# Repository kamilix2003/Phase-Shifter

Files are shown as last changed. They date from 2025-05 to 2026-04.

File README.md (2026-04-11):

# Interface for MAPS-010144 digital phase shifter

## Description

STM32G0B01 based board for controlling daisy-chained digital phase shifter via SPI-like serial interface. User can interface with the board either by buttons and LEDs on the board or via virtual serial port over USB, communication over serial port is realized using simple TLV protocol. The board is providing bipolar supply for the phase shifters.

<p align=center>
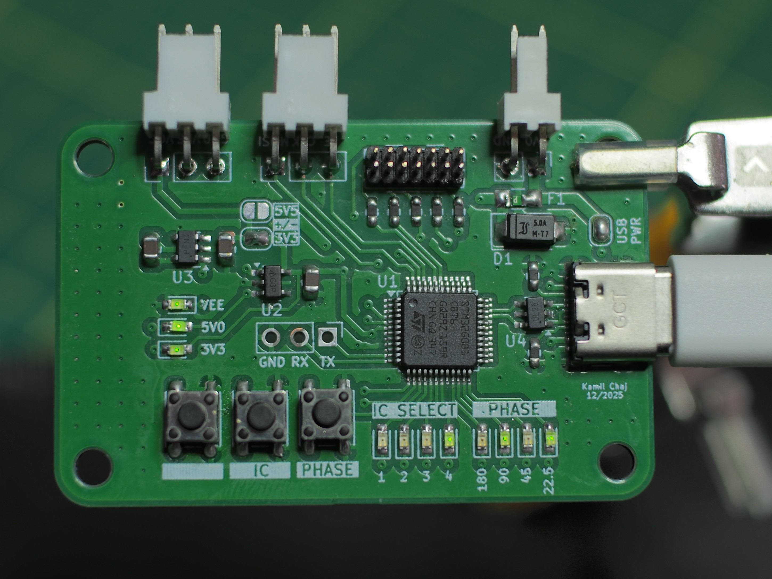
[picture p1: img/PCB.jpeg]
    
</p>

<!-- ![PCB photo](img/PCB.jpeg) -->

### Repository contents
- [KiCAD](KiCAD) - ECAD projects of all desinged PCBs for the project
- [python_api](python_api) - Simple python api for communicating with the controller via serial port
- [Src](Src) - Firmware source code separated from generated STM32 project
- [phase_shifter_measurements](phase_shifter_mesurements) - Measuremented scattering parameters of the phase shifter

## Firmware 

<p align=center>
    
</p>

<!-- ![firmware_architecture](img/firmware_architecture.drawio.svg) -->

### Serial communication

Available commands:
| **T**ype | **L**ength [bytes] | **V**alue | Description |
|---|---|---|---|
| 0x02 | 1 | command id | Ack |
| 0x10 | 4 | phase shifts (0 - 15) | Set phase |
| 0x11 | 0 | - | Transmit |
| 0x12 | 1 | latch state | Latch state |

After each message microcontroller should send ACK message with payload containing command id of original message

Example routine to set new phase delay:
1. `0x12 0x01 0x00` - make sure that latch is set low in order to accept data via serial interface
1. `0x10 0x04 0x04 0x02 0x0f 0x08` - send phase shifts to the controller
1. `0x11 0x00` - transmit phase shifts via SPI to the phase shifters
1. `0x12 0x01 0x01` - set latch to update phase shift 
1. `0x12 0x01 0x00` - reset latch

### Buttons and LEDs

The board is equiped in 3 tactile buttons and two 4-led displays where each display shows according to the silkscreen description either currently selected phase shifter or phase shift set for the selected phase shifter.
Buttons have following functions starting from the left most button:
- On short press transmits current phase shifter configuration over SPI
- On short press cycles through 4 phase shifters, on long press sets all phase shifters to 0
- On short press increments phase delay, on long press set current phase shifter to 0

<!-- # MAPS-010144 Phase Shifter Interface as Part of Phased Antenna Array

## Description

A microcontroller serves as an interface for phase control, managing multiple phase shifters connected in a daisy chain via SPI. Bidirectional communication between the PC and MCU is established via UART/USB.

## Goals

in **bold** features in scope of SKM project

- **Serial interface with IC via SPI peripheral**
- **PC-MCU communication by UART/USB (virtual COM)**
- **Controlling multiple phase shifter in daisy chain**
- Python API for controlling beam direction
- I2C bus for communication with multiple arrays where one becomes master

## Block diagram

![block diagram](img/SKM.drawio.svg)

## Docs

- [Specification](./docs/Specification.md)
- [Report](./docs/SKM_Report_Kamil_Chaj.pdf) -->

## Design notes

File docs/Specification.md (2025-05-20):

# Specification

## Communication sequence

```mermaid
sequenceDiagram
    PC->>+MCU: UART - initial frame
    MCU->>MCU: Error detection
    MCU->>PC: Report error / Response
    PC->>MCU: 
    loop from N to 1
    MCU->>+IC: SPI: phase setting
    MCU->>+IC: 
    MCU->>+IC: 
    end
    MCU->>-PC: Success / Error
```

## System diagram

```mermaid
flowchart LR

UART -- RX --> UART_b
UART_b -- End of transmission --> CRC
CRC -- Success ---> Process_frame

Process_frame -- TX --> UART
Process_frame --> SPI_b
SPI_b --> SPI
Process_frame -- Start TX --> SPI

Process_frame[Frame processing]
UART_b[UART buffer]
SPI_b[SPI buffer]

```

## SPI

Serial communication specification according to MAPS-010144 datasheet[^2]

|Pin|Description|
|---|---|
|SERIN|MOSI|
|SEROUT|MSIO - connected to the next IC|
|CLK|Clock|
|LE|Output (phase) stays constant when set LOW|
|P/S|Parallel/Serial select, HIGH for Serial|

Internal register of the IC has 6 bits, where most significant bit represent most significant phase shift

|Option|Value|
|---|---|
|Data size|6 Bits|
|Frist bit|MSB first|
|Clock period|> 100ns|
|CPOL|LOW|
|CPHA|LOW|

## UART / USB

### Frame

Full frame is built of multiple bytes where:

|Bytes |Function|
|---|---|
|Byte 1|Command ID|
|Byte 2|Payload size|
|Byte 3|Data 0|
|Byte 4|Data 1|
|Byte ...|...|
|Byte N|Data N|
|Byte N + 1|CRC|

### Commands

#### Send phase shift buffer

- Data n - phase shifter address
- Data n+1 - phase shift

#### Request phase shift buffer

- Data n - phase shifter address

#### Load phase shift buffer

- No data

#### Clear phase shift buffer

- No data

#### Error

- Data n - contains error code

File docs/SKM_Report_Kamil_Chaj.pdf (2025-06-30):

## Phase Shifter Interface

Standardy Komunikacji Międzyukładowej w modułowych systemach wbudowanych

Kamil Chaj

## 1 Introduction

This project is a part of the phased array antenna and the goal is to create a way to programmable control multiple phase shifters. Phase shifters can be controlled directly by accessing all control bits in parallel, or they can be controlled via the SPI-like protocol, which enables controlling multiple phase shifters utilizing minimal pin count. The interface with the microcontroller will be implemented using UART.

## 2 Selected MCU

The STM32 NUCLEO-G0B1RE evaluation board was chosen for this project, the main requirement was an integrated USB controller to minimize the element count on the future printed circuit board. Also, the G0 series MCU was chosen because of low price and no need for high performance of specific peripherals other than USB and SPI.

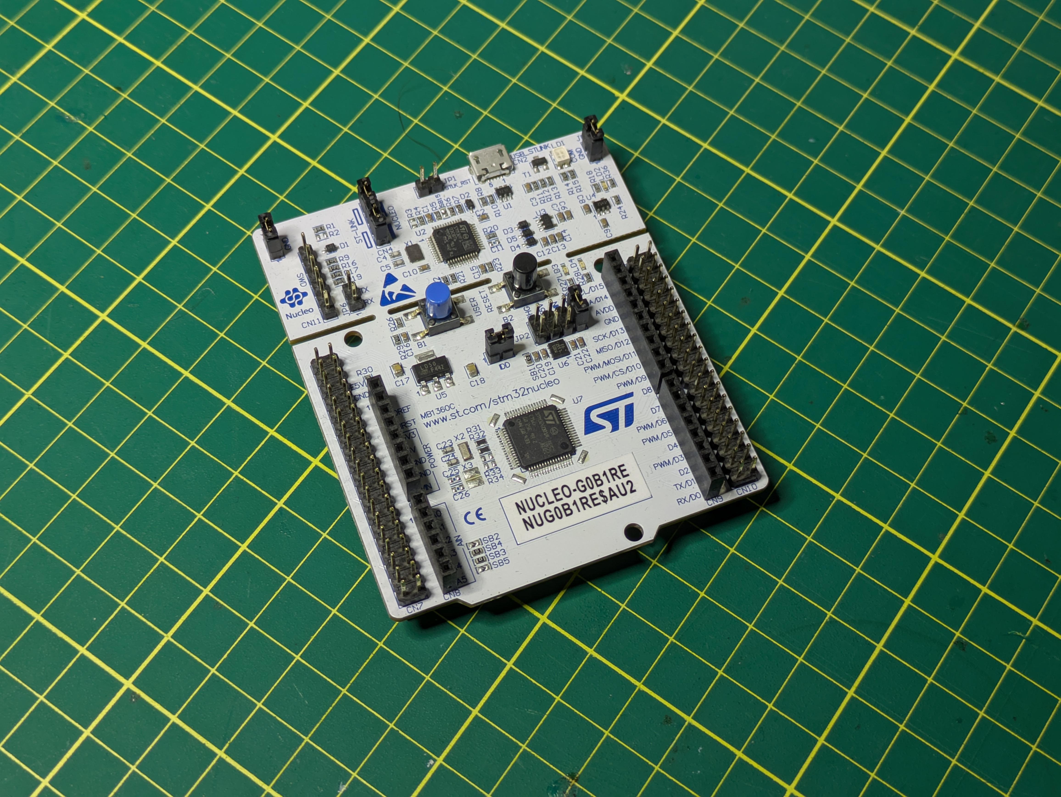
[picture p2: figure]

Figure 1: NUCLEO development board

## 3 SPI protocol

MAPS-010144 (https://cdn.macom.com/datasheets/MAPS-010144.pdf) phase shifter has a 6-bit shift register which corresponds to quantized phase shift, in the case of this particular phase shifter 2 least significant bits are not used because the maximum resolution is 4-bit. In order to update the phase shift from the register to the actual phase shift, the LE pin must be set. Phase shifters are equipped in both SERIN and SEROUT pins which allow multiple ICs to be connected in a daisy chain.
SPI peripheral was configured according to the phase shifter data sheet, data size was set at 6 bits and the transmission starts from the least significant bit; also, the baud rate was set to just 250 Kbits per second, which is much slower than what the IC can handle but what allowed easier debugging with my current measurement equipment.

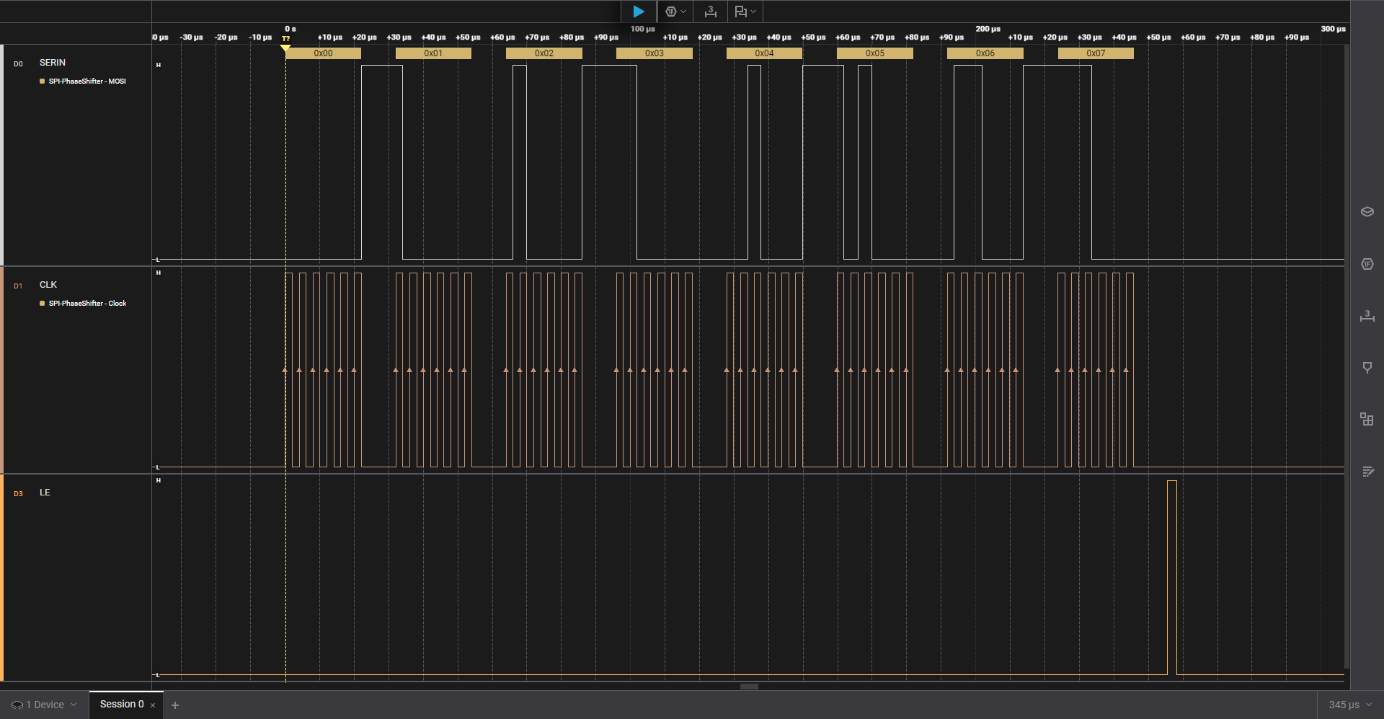
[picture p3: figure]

Figure 2: SPI communication captured with logic analyzer

## 4 USB CDC virtual COM port

Communication over virtual COM port is implemented using the USB_DEVICE middleware provided with the STM32CUBE environment, the middleware is set in the Communication Device Class (CDC) mode. Using this middleware allows for simple communication with a PC identical to UART.

### 4.1 Communication protocol

Byte 0 | Byte 1 | Byte 2 | Byte... | Byte N | Byte N+1 | Byte N+2
COMMAND ID | DATA SIZE | DATA 0 | ... | DATA N | CRC | END

Table 1: Data format

Name | Hex value | Description
OK | 0x00 | transmission successful
ECHO | 0x01 | return the same command
ERROR | 0xff | transmission failed
PHASE SHIFTER COUNT | 0x03 | set number of phase shifters
SEND BUFFER | 0x10 | begin SPI transmission
SET BUFFER | 0x11 | send new buffer
GET BUFFER | 0x12 | request current buffer
GET BUFFER RE | 0x13 | response with buffer
CLEAR BUFFER | 0x14 | set buffer to 0

Table 2: Commands

### 4.2 Cyclic redundancy check

CRC value on MCU side is calculated using integrated CRC calculation unit and the same algorithm is implement on PC side.

## 5 Implementation

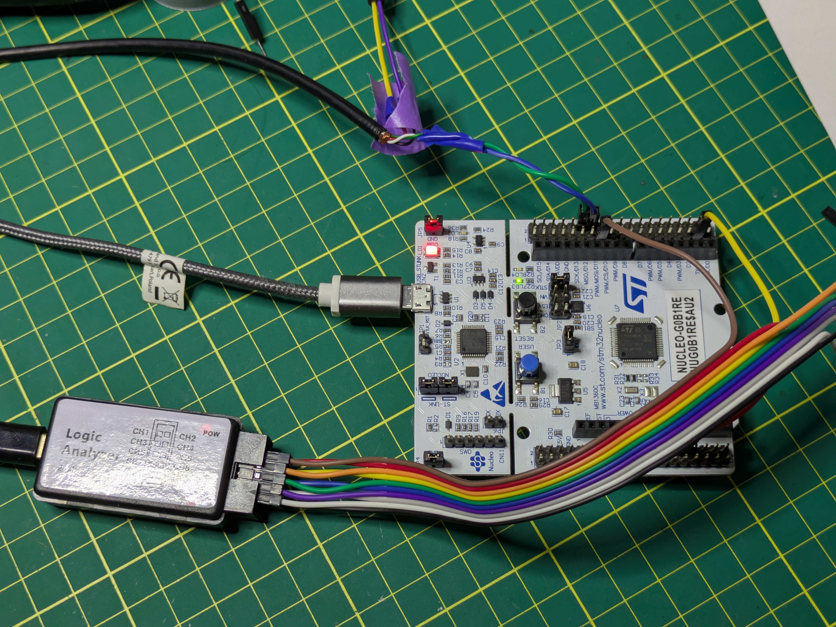
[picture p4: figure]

Figure 3: Test setup

### 5.1 Peripheral initialization

The first step of implementation was setting up the required peripherals in STM32CubeMX:

- TIM1 - timing LE pulse
- SPI1 - communication with phase shifter
- USART2 - ST-LINK virtual com port for debugging
- USB_DRD_FS - integrated USB peripheral
- CRC - CRC calculation unit
- USB_DEVICE - Middleware for USB

### 5.2 Phase shifter interface

As for typical embedded program structure, I create a typedef struct phase_shifter which holds all necessary handles and variables, and typedef enum phase_shifter_status for status type. after defining those types, I created basic functions that implement the following actions: initiation of phase_shifter, setting, getting and clearing buffer, setting the number of connected phase shifters and starting transmission.

### 5.3 PC-MCU communication

Similarly as in the previous section, I defined typedef struct command, typedef struct interface and typedef enum interface_status. The command struct is used to store and create commands in a more convenient way during processing.
Functions used for communication:
- recieve_command - dissects buffer and populates variables in command struct, verifies CRC value
- transmit_command - assembles buffer from command struct and appends CRC value
- process_command - handles received commands and sends responses to the sender

The entire communication is PC-driven, which means that MCU does something in response to the PC.

### 5.4 Python API

As mentioned in the introduction, the goal is to create a way to programmable control phase shifter therefore, I created a simple Python program that allows for sending and receiving data.

### 5.5 Block diagram

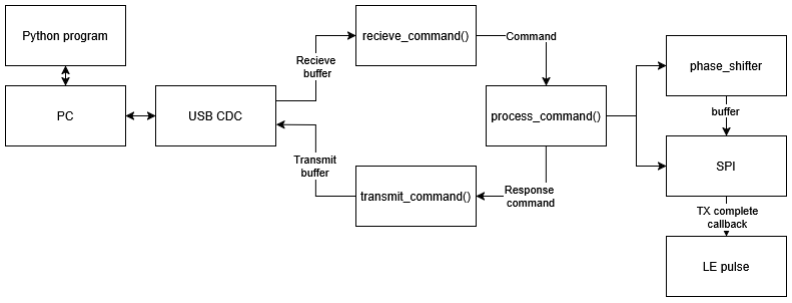
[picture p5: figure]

Figure 4: Block diagram of the program

## 6 Conclusions

This project successfully demonstrates a complete system for controlling multiple integrated circuits using embedded communication protocols. By integrating USB CDC communication, a structured command protocol, SPI data transmission, and a Python-based control API, a flexible and scalable interface was established. The modular software structure, including clear abstractions for the phase shifter interface and communication protocol, enhances maintainability and potential for future expansion.
Overall, the project fulfills its intended goals and provides a solid foundation for further development and integration into more complex RF systems.
All code available on GitHub (https://github.com/kamilix2003/phase-shifter)

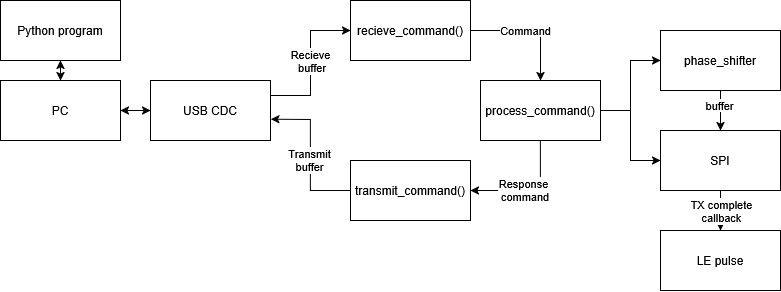
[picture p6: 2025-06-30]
img/SKM.drawio.png

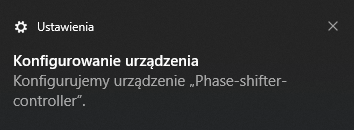
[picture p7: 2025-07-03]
img/port_name.png

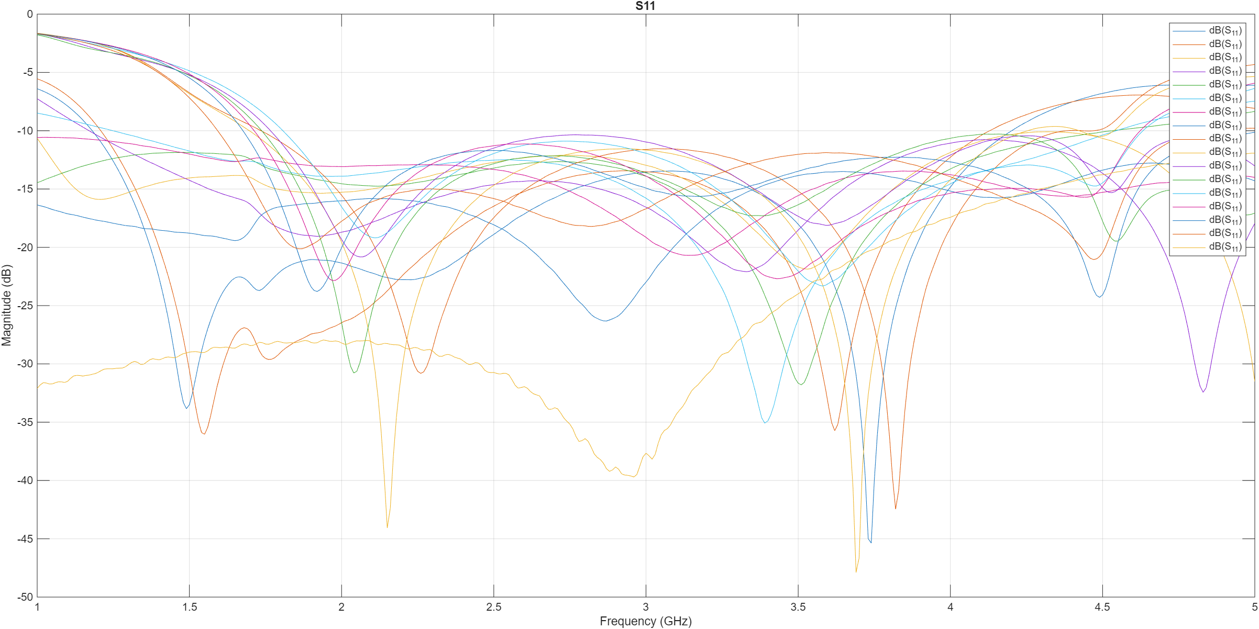
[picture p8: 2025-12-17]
phase_shifter_mesurements/s11.png

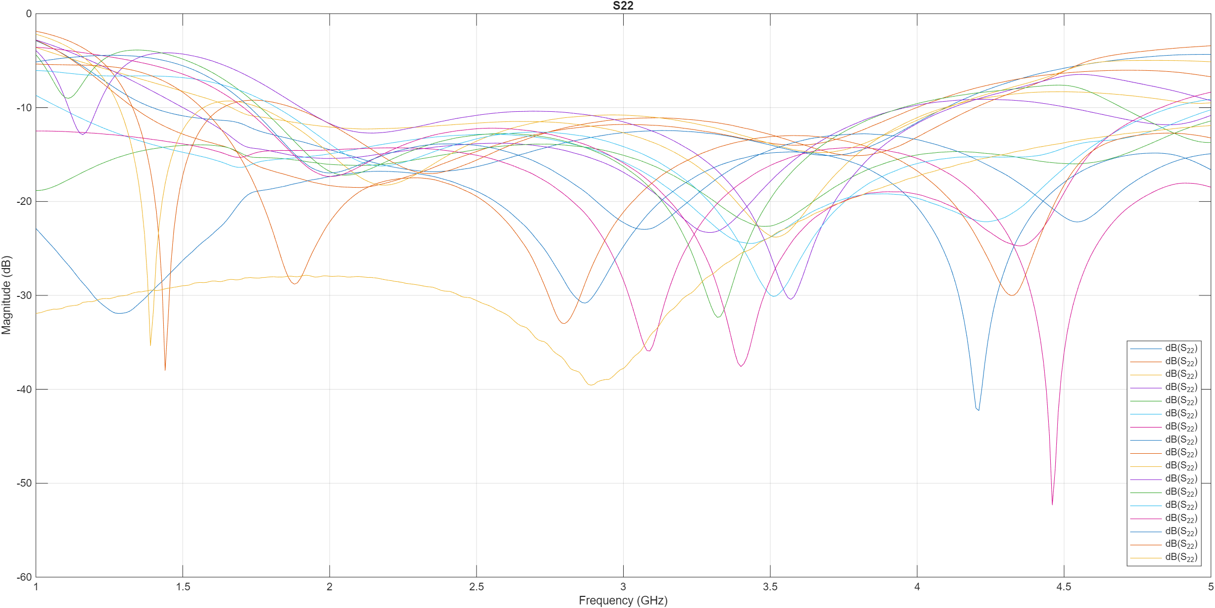
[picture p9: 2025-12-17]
phase_shifter_mesurements/s22.png

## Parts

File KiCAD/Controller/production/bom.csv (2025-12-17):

Designator | Footprint | Quantity | Value | LCSC Part #
C1, C10, C2, C3, C4, C5, C6, C7, C8, C9 | 0805 | 10 | 4.7u
C11, C12, C13, C14, C15, C16 | 0603 | 6 | 100n
D1 | D_SMA | 1 | SMAJ5.0A
D10, D11, D12, D2, D3, D4, D5, D6, D7, D8, D9 | 0603 | 11 | LED
F1 | 1206 | 1 | Polyfuse
J1 | PinHeader_2x07_P1.27mm_Vertical | 1 | Conn_ST_STDC14
J2 | USB_C_Receptacle_GCT_USB4105-xx-A_16P_TopMnt_Horizontal | 1 | USB_C_Receptacle_USB2.0_16P
J3 | PinHeader_1x02_P2.54mm_Vertical | 1 | Conn_01x02_Pin
J4, J5, J6 | PinHeader_1x03_P2.54mm_Vertical | 3 | Conn_01x03_Pin
R1, R2, R3, R4, R5 | 0603 | 5 | 100
R10, R11, R12, R13, R14, R15, R16, R17, R18, R6, R7, R8, R9 | 0603 | 13 | 5.1k
SW1, SW2, SW3 | SW_SPST_PTS647_Sx38 | 3 | SW_Push
U1 | LQFP-48_7x7mm_P0.5mm | 1 | STM32G0B1CBTx
U2 | SOT-23-5 | 1 | AP2127K-3.3
U3 | SOT-23-5 | 1 | TPS60403DBV
U4 | SOT-23-6 | 1 | USBLC6-2SC6

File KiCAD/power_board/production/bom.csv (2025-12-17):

Designator | Footprint | Quantity | Value | LCSC Part #
C1, C2, C3, C4, C5, C6, C7, C8 | 0805 | 8 | 4.7u
D1 | D_SMA | 1 | SMAJ5.0A
D2, D4 | 0603 | 2 | LED
F1 | 1206 | 1 | Polyfuse
J1 | PinHeader_1x03_P2.54mm_Vertical | 1 | Conn_01x03_Pin
J2 | PinHeader_1x02_P2.54mm_Vertical | 1 | Conn_01x02_Pin
R1, R3 | 0603 | 2 | 5.1k
U1 | SOT-23-5 | 1 | TPS60403DBV
U2 | SOT-23-5 | 1 | AP2127K-3.3

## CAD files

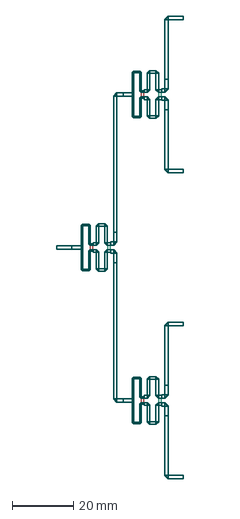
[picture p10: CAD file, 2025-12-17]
KiCAD/Feed_network/4_way_divider.dxf
41.4 x 151.1 mm

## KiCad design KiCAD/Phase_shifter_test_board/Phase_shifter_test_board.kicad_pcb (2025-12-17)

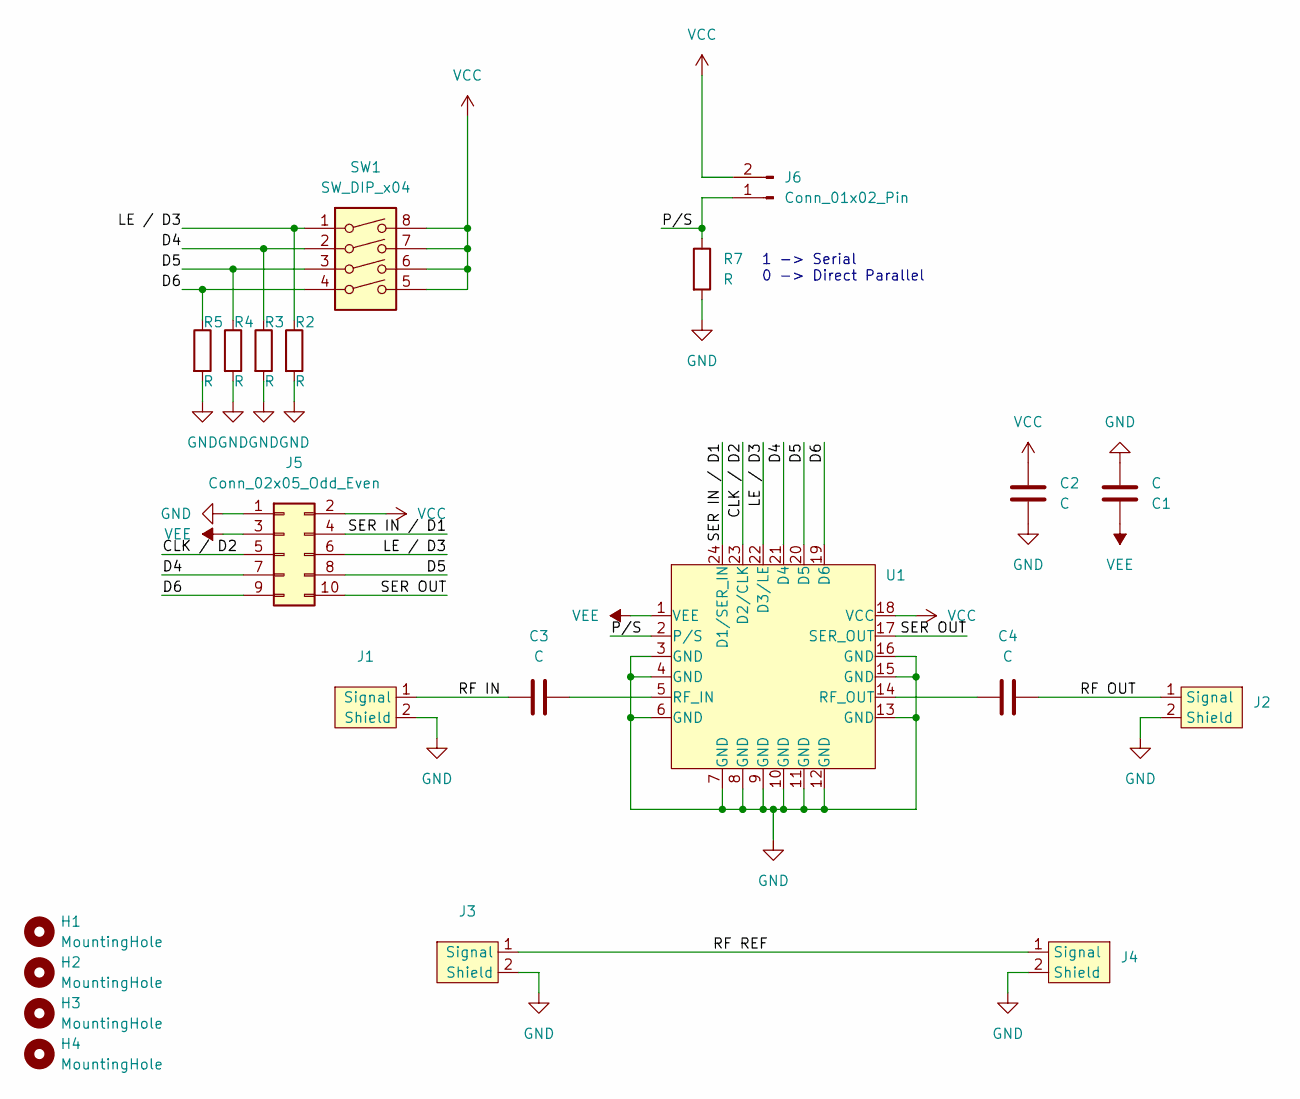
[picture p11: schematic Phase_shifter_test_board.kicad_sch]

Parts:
C1, C2, C3, C4: C; C_0603_1608Metric_Pad1.08x0.95mm_HandSolder
H1, H2, H3, H4: MountingHole; MountingHole_3.2mm_M3
J1, J2, J3, J4: Conn
J5: Conn_02x05_Odd_Even; PinHeader_2x05_P2.54mm_Vertical
J6: Conn_01x02_Pin; PinHeader_1x02_P2.54mm_Vertical
R2, R3, R4, R5, R7: R; R_0603_1608Metric_Pad0.98x0.95mm_HandSolder
SW1: SW_DIP_x04; SW_DIP_SPSTx04_Slide_9.78x12.34mm_W7.62mm_P2.54mm
U1: QFN-24_EP_4x4_Pitch0.5mm

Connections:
/CLK / D2: J5.5, U1.23 (D2/CLK)
/D4: J5.7, R3.1, SW1.2, U1.21 (D4)
/D5: J5.8, R4.1, SW1.3, U1.20 (D5)
/D6: J5.9, R5.1, SW1.4, U1.19 (D6)
/LE / D3: J5.6, R2.1, SW1.1, U1.22 (D3/LE)
/P/S: J6.1, R7.1, U1.2 (P/S)
/RF IN: C3.1, J1.1 (Signal)
/RF OUT: C4.2, J2.1 (Signal)
/RF REF: J3.1 (Signal), J4.1 (Signal)
/SER IN / D1: J5.4, U1.24 (D1/SER_IN)
/SER OUT: J5.10, U1.17 (SER_OUT)
GND: C1.2, C2.2, J1.2 (Shield), J2.2 (Shield), J3.2 (Shield), J4.2 (Shield), J5.1, R2.2, R3.2, R4.2, R5.2, R7.2, U1.3 (GND), U1.4 (GND), U1.6 (GND), U1.7 (GND), U1.8 (GND), U1.9 (GND), U1.10 (GND), U1.11 (GND), U1.12 (GND), U1.13 (GND), U1.15 (GND), U1.16 (GND)
unnamed: C3.2, U1.5 (RF_IN)
unnamed: C4.1, U1.14 (RF_OUT)
VCC: C2.1, J5.2, J6.2, SW1.5, SW1.6, SW1.7, SW1.8, U1.18 (VCC)
VEE: C1.1, J5.3, U1.1 (VEE)

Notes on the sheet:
1 -> Serial 0 -> Direct Parallel

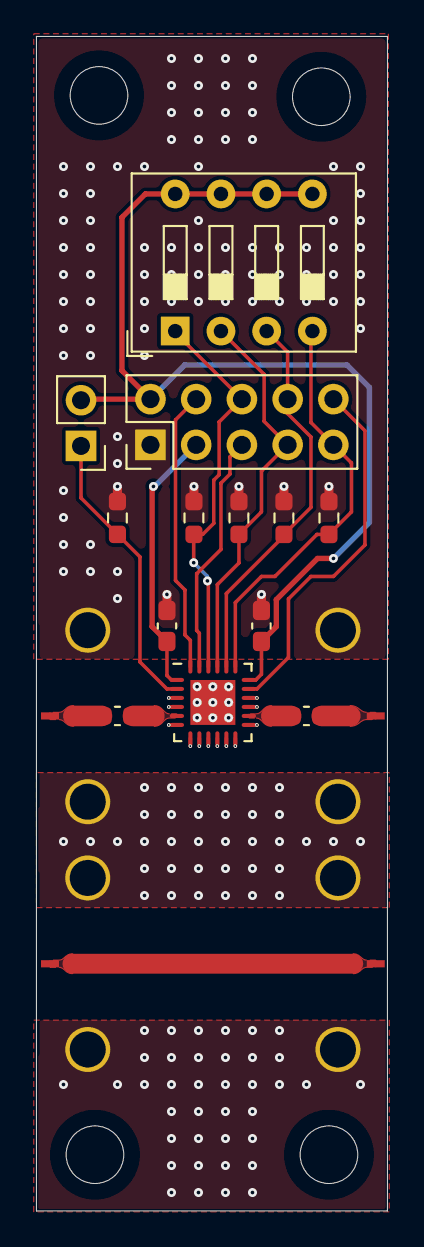
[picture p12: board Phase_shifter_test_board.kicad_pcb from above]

Board: 2 copper layers, 19.5 x 65.2 mm, 21 parts (0 on the bottom side), 16 nets.

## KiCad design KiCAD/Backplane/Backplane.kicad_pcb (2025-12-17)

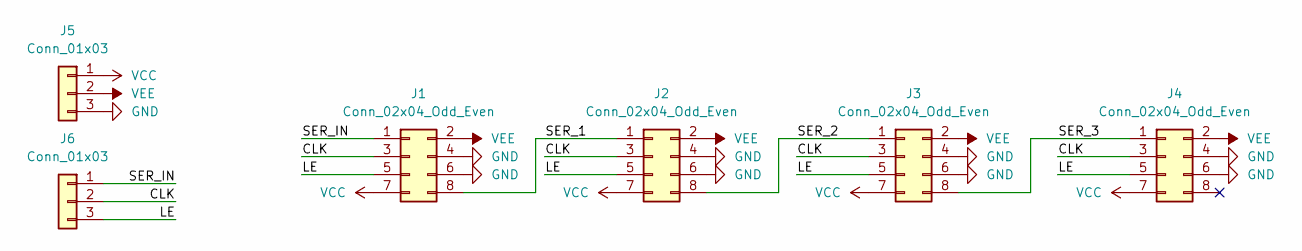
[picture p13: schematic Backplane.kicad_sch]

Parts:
J1, J2, J3, J4: Conn_02x04_Odd_Even; PinSocket_2x04_P2.54mm_Vertical
J5, J6: Conn_01x03; PinHeader_1x03_P2.54mm_Horizontal

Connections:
/CLK: J1.3, J2.3, J3.3, J4.3, J6.2
/LE: J1.5, J2.5, J3.5, J4.5, J6.3
/SER_1: J1.8, J2.1
/SER_2: J2.8, J3.1
/SER_3: J3.8, J4.1
/SER_IN: J1.1, J6.1
GND: J1.4, J1.6, J2.4, J2.6, J3.4, J3.6, J4.4, J4.6, J5.3
VCC: J1.7, J2.7, J3.7, J4.7, J5.1
VEE: J1.2, J2.2, J3.2, J4.2, J5.2

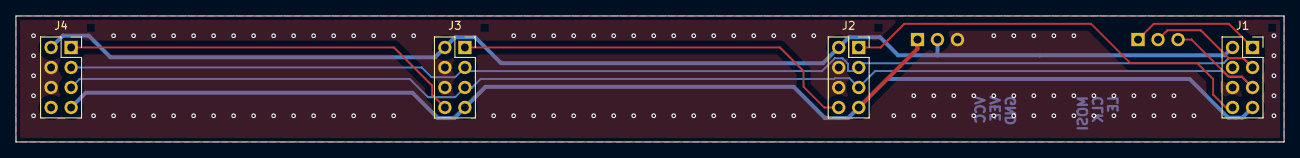
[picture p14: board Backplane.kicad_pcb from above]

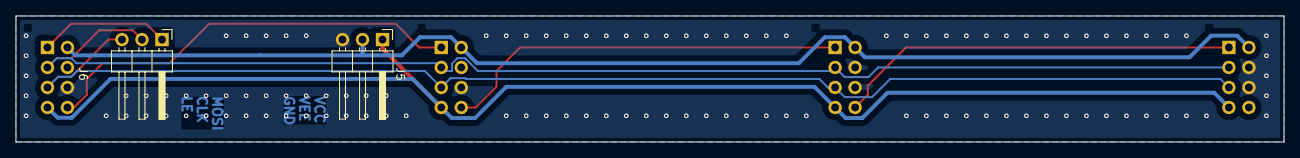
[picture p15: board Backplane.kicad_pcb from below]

Board: 2 copper layers, 161.0 x 16.0 mm, 6 parts (2 on the bottom side), 9 nets.

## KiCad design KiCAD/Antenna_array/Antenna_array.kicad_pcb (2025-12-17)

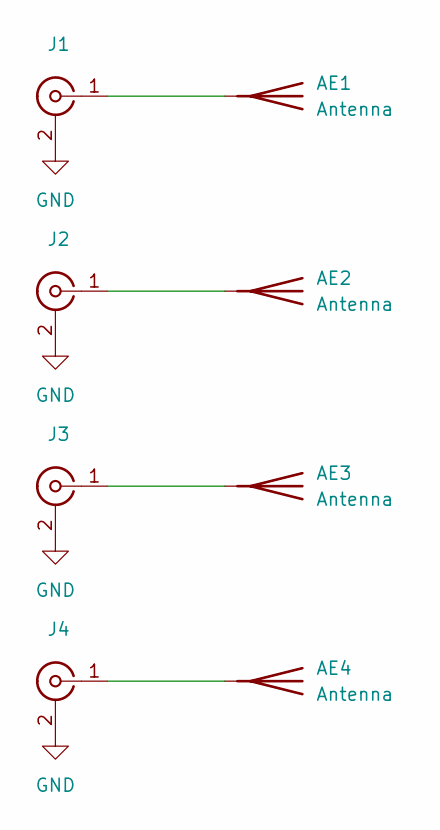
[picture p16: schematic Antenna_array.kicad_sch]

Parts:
AE1, AE2, AE3, AE4: Antenna; patch
J1, J2, J3, J4: Conn

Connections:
GND: J1.2, J2.2, J3.2, J4.2
unnamed: AE1.1 (A), J1.1
unnamed: AE2.1 (A), J2.1
unnamed: AE3.1 (A), J3.1
unnamed: AE4.1 (A), J4.1

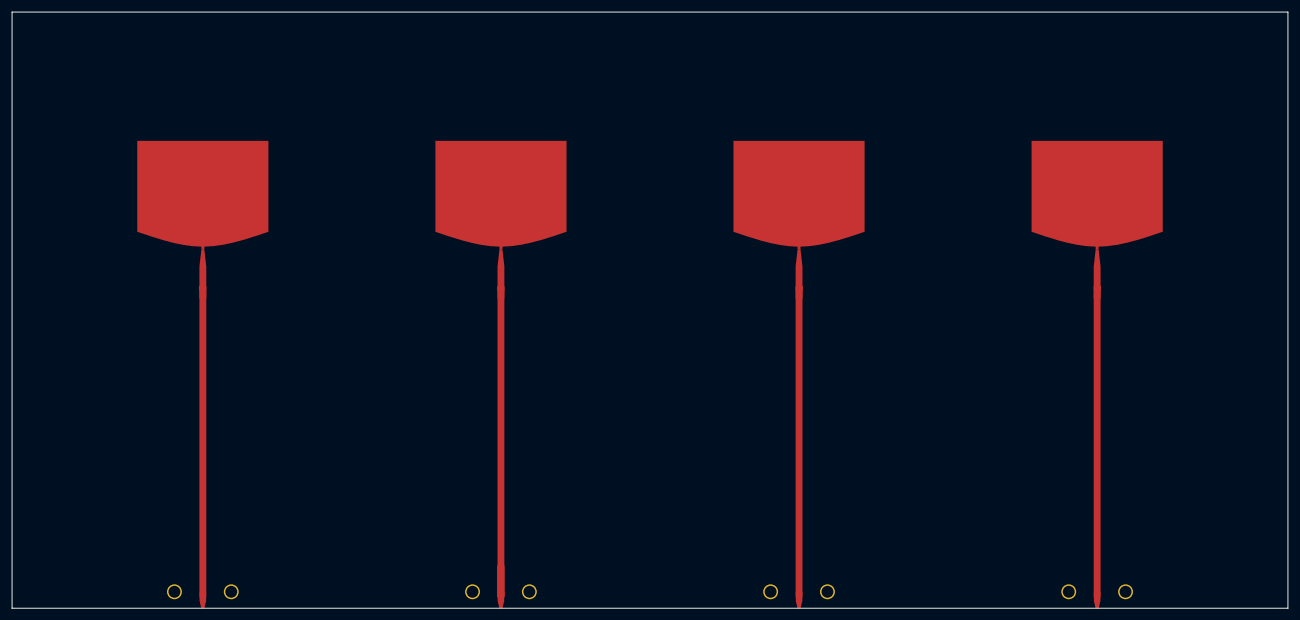
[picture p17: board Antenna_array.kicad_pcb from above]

Board: 2 copper layers, 214.0 x 100.0 mm, 8 parts (0 on the bottom side), 5 nets.

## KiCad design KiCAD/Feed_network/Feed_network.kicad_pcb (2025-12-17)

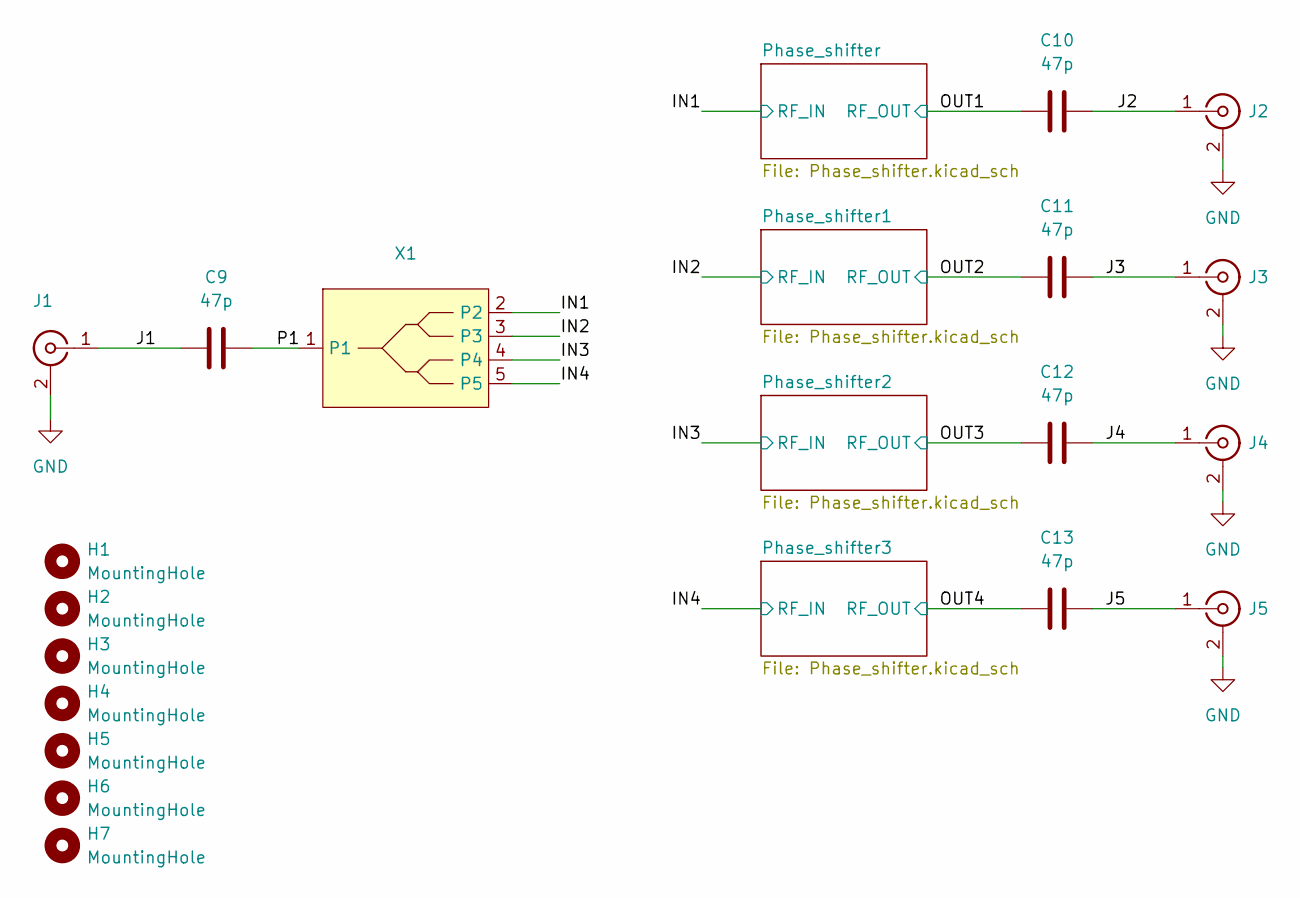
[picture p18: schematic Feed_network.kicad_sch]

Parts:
C9, C10, C11, C12, C13: 47p; C_0603_1608Metric_Pad1.08x0.95mm_HandSolder
H1, H2, H3, H4, H5, H6, H7: MountingHole; MountingHole_3.2mm_M3
J1, J2, J3, J4, J5: Conn
X1: 4_way_divider

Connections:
/IN1: X1.2; also elsewhere on the board
/IN2: X1.3; also elsewhere on the board
/IN3: X1.4; also elsewhere on the board
/IN4: X1.5; also elsewhere on the board
/J1: C9.1, J1.1
/J2: C10.1, J2.1
/J3: C11.1, J3.1
/J4: C12.1, J4.1
/J5: C13.1, J5.1
/OUT1: C10.2; also elsewhere on the board
/OUT2: C11.2; also elsewhere on the board
/OUT3: C12.2; also elsewhere on the board
/OUT4: C13.2; also elsewhere on the board
/P1: C9.2, X1.1
GND: J1.2, J2.2, J3.2, J4.2, J5.2; also elsewhere on the board

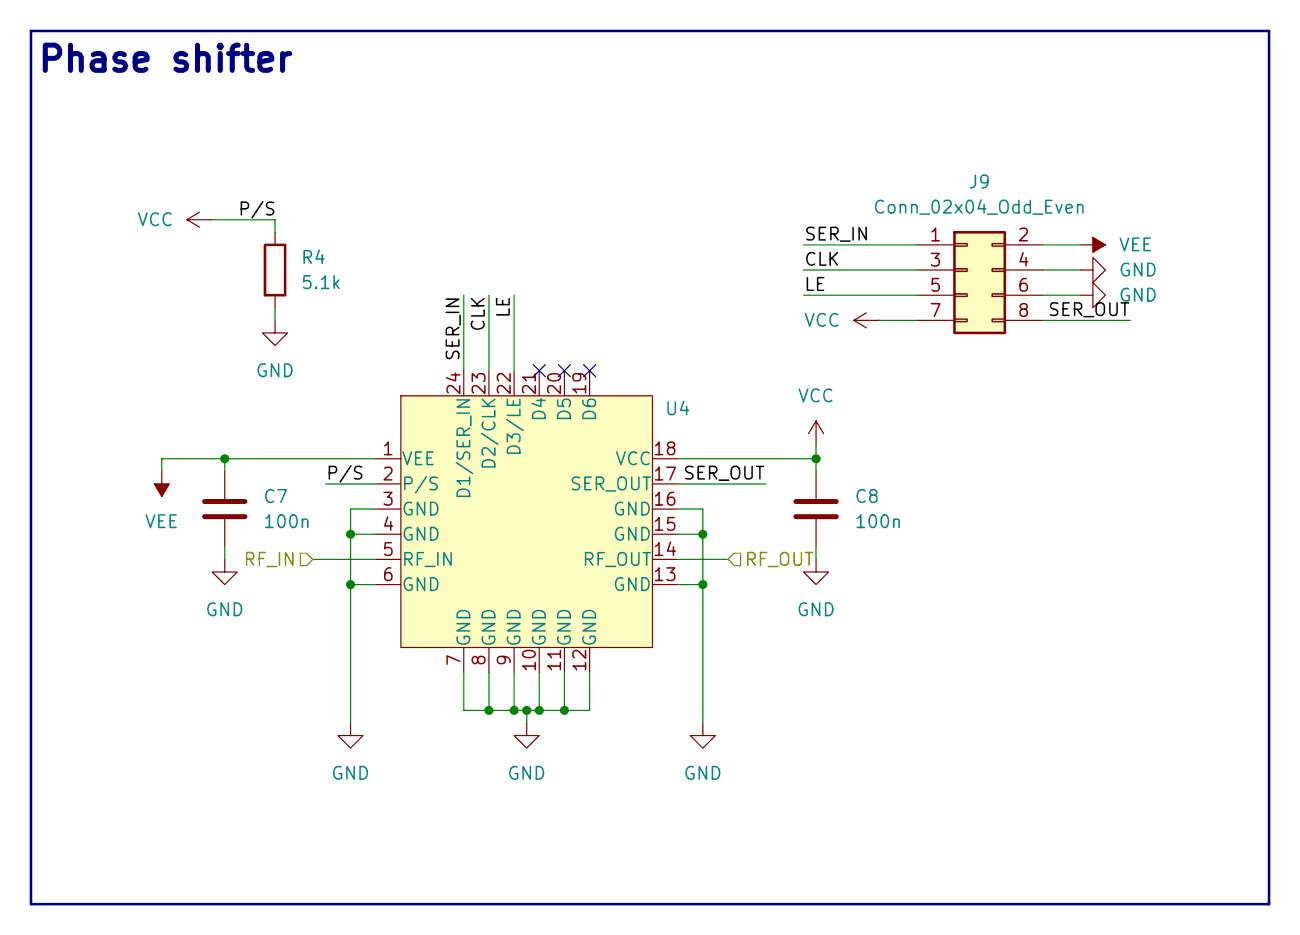
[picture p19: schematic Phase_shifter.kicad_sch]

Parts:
C7, C8: 100n; C_0603_1608Metric_Pad1.08x0.95mm_HandSolder
J9: Conn_02x04_Odd_Even; PinHeader_2x04_P2.54mm_Vertical
R4: 5.1k; R_0603_1608Metric_Pad0.98x0.95mm_HandSolder
U4: QFN-24_EP_4x4_Pitch0.5mm

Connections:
/IN4: U4.5 (RF_IN); also elsewhere on the board
/OUT4: U4.14 (RF_OUT); also elsewhere on the board
/Phase_shifter3/CLK: J9.3, U4.23 (D2/CLK)
/Phase_shifter3/LE: J9.5, U4.22 (D3/LE)
/Phase_shifter3/SER_IN: J9.1, U4.24 (D1/SER_IN)
/Phase_shifter3/SER_OUT: J9.8, U4.17 (SER_OUT)
GND: C7.2, C8.2, J9.4, J9.6, R4.2, U4.3 (GND), U4.4 (GND), U4.6 (GND), U4.7 (GND), U4.8 (GND), U4.9 (GND), U4.10 (GND), U4.11 (GND), U4.12 (GND), U4.13 (GND), U4.15 (GND), U4.16 (GND); also elsewhere on the board
VCC: C8.1, J9.7, R4.1, U4.2 (P/S), U4.18 (VCC); also elsewhere on the board
VEE: C7.1, J9.2, U4.1 (VEE); also elsewhere on the board

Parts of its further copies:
C1, C2, C3, C4, C5, C6: 100n; C_0603_1608Metric_Pad1.08x0.95mm_HandSolder
J6, J7, J8: Conn_02x04_Odd_Even; PinHeader_2x04_P2.54mm_Vertical
R1, R2, R3: 5.1k; R_0603_1608Metric_Pad0.98x0.95mm_HandSolder
U1, U2, U3: QFN-24_EP_4x4_Pitch0.5mm

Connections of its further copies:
/IN1: U1.5 (RF_IN); also elsewhere on the board
/IN2: U2.5 (RF_IN); also elsewhere on the board
/IN3: U3.5 (RF_IN); also elsewhere on the board
/OUT1: U1.14 (RF_OUT); also elsewhere on the board
/OUT2: U2.14 (RF_OUT); also elsewhere on the board
/OUT3: U3.14 (RF_OUT); also elsewhere on the board
/Phase_shifter1/CLK: J7.3, U2.23 (D2/CLK)
/Phase_shifter1/LE: J7.5, U2.22 (D3/LE)
/Phase_shifter1/SER_IN: J7.1, U2.24 (D1/SER_IN)
/Phase_shifter1/SER_OUT: J7.8, U2.17 (SER_OUT)
/Phase_shifter2/CLK: J8.3, U3.23 (D2/CLK)
/Phase_shifter2/LE: J8.5, U3.22 (D3/LE)
/Phase_shifter2/SER_IN: J8.1, U3.24 (D1/SER_IN)
/Phase_shifter2/SER_OUT: J8.8, U3.17 (SER_OUT)
/Phase_shifter/CLK: J6.3, U1.23 (D2/CLK)
/Phase_shifter/LE: J6.5, U1.22 (D3/LE)
/Phase_shifter/SER_IN: J6.1, U1.24 (D1/SER_IN)
/Phase_shifter/SER_OUT: J6.8, U1.17 (SER_OUT)
GND: C1.2, C2.2, C3.2, C4.2, C5.2, C6.2, J6.4, J6.6, J7.4, J7.6, J8.4, J8.6, R1.2, R2.2, R3.2, U1.3 (GND), U1.4 (GND), U1.6 (GND), U1.7 (GND), U1.8 (GND), U1.9 (GND), U1.10 (GND), U1.11 (GND), U1.12 (GND), U1.13 (GND), U1.15 (GND), U1.16 (GND), U2.3 (GND), U2.4 (GND), U2.6 (GND), U2.7 (GND), U2.8 (GND), U2.9 (GND), U2.10 (GND), U2.11 (GND), U2.12 (GND), U2.13 (GND), U2.15 (GND), U2.16 (GND), U3.3 (GND), U3.4 (GND), U3.6 (GND), U3.7 (GND), U3.8 (GND), U3.9 (GND), U3.10 (GND), U3.11 (GND), U3.12 (GND), U3.13 (GND), U3.15 (GND), U3.16 (GND); also elsewhere on the board
VCC: C2.1, C4.1, C6.1, J6.7, J7.7, J8.7, R1.1, R2.1, R3.1, U1.2 (P/S), U1.18 (VCC), U2.2 (P/S), U2.18 (VCC), U3.2 (P/S), U3.18 (VCC); also elsewhere on the board
VEE: C1.1, C3.1, C5.1, J6.2, J7.2, J8.2, U1.1 (VEE), U2.1 (VEE), U3.1 (VEE); also elsewhere on the board

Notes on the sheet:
Phase shifter

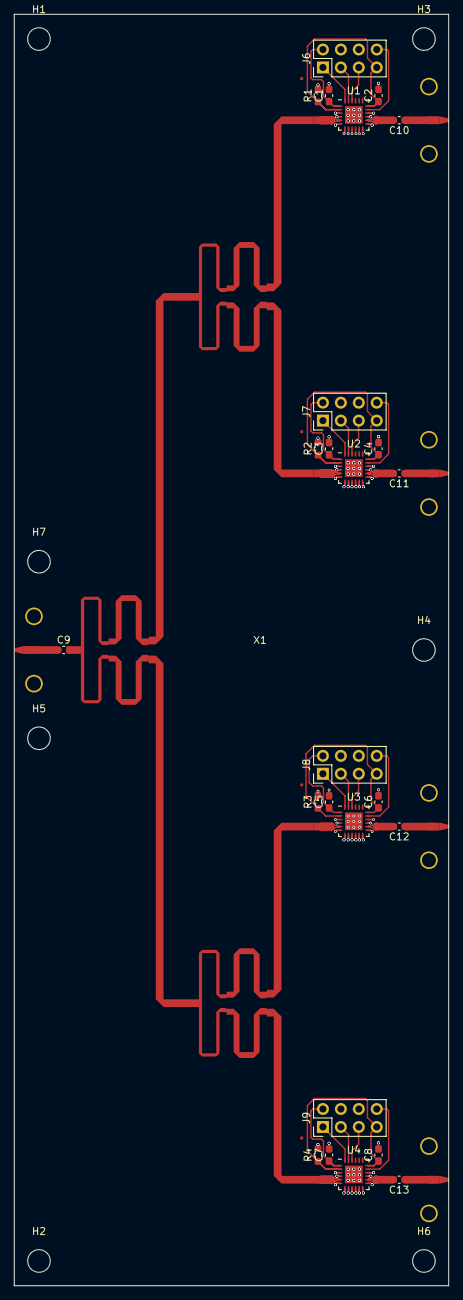
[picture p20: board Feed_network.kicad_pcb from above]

Board: 2 copper layers, 61.5 x 180.0 mm, 38 parts (0 on the bottom side), 33 nets.

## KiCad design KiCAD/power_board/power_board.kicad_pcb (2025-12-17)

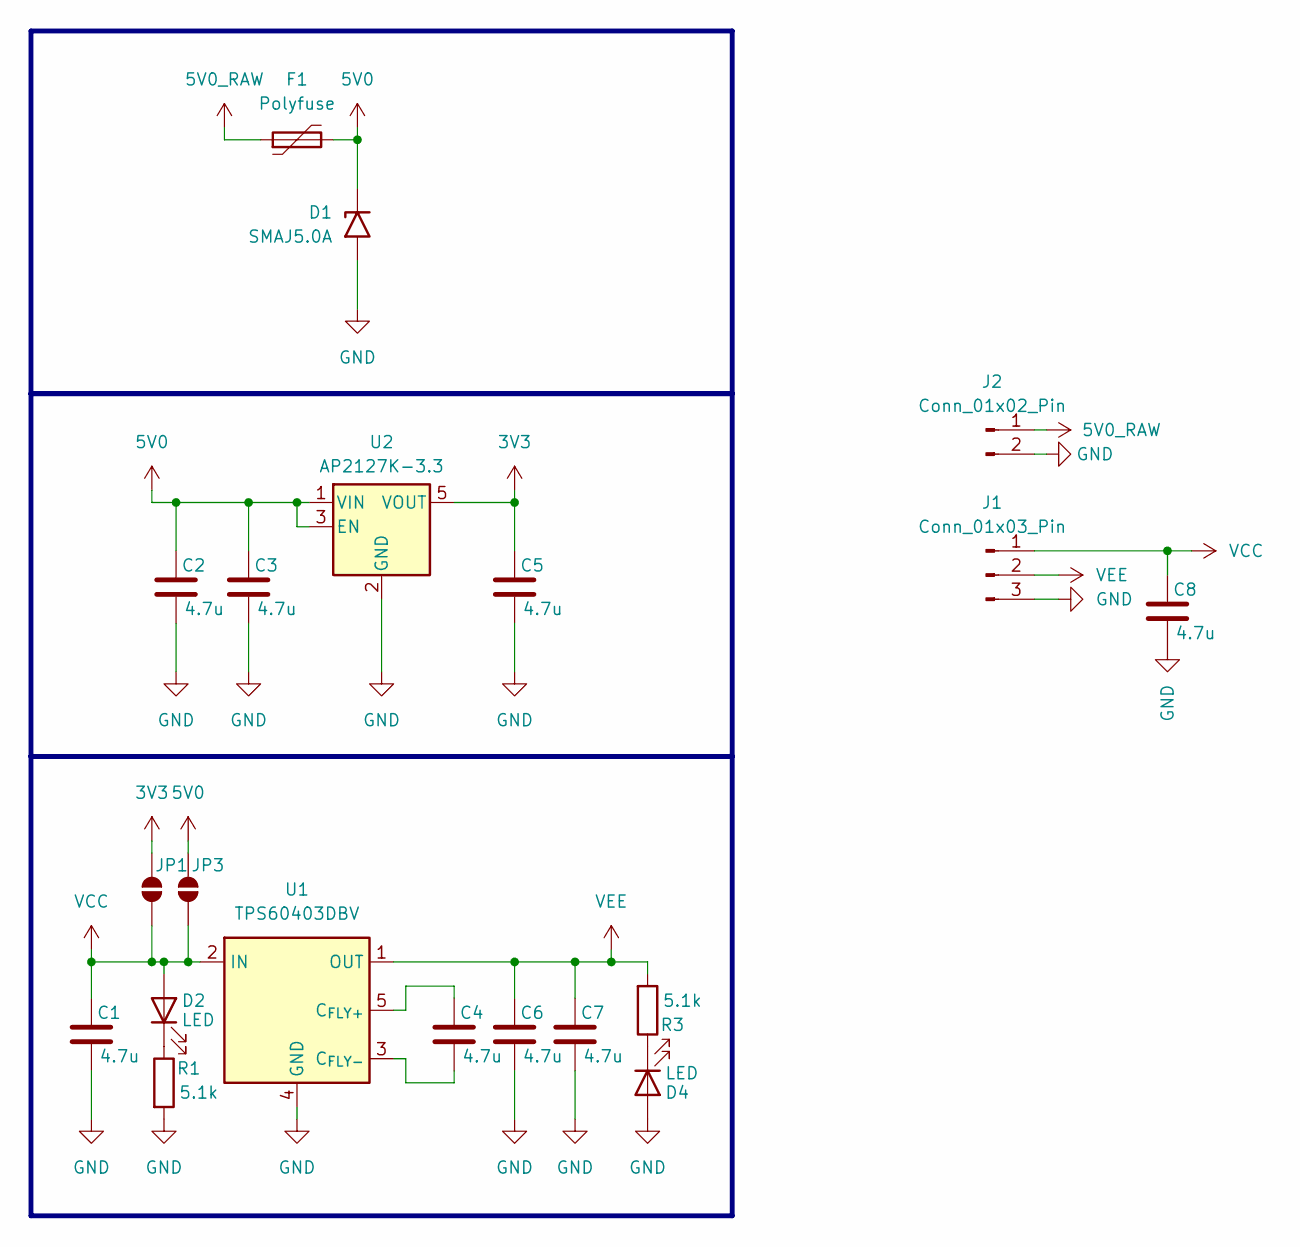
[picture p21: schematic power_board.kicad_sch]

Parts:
C1, C2, C3, C4, C5, C6, C7, C8: 4.7u; C_0805_2012Metric_Pad1.18x1.45mm_HandSolder
D1: SMAJ5.0A; D_SMA
D2, D4: LED; LED_0603_1608Metric_Pad1.05x0.95mm_HandSolder
F1: Polyfuse; Fuse_1206_3216Metric_Pad1.42x1.75mm_HandSolder
J1: Conn_01x03_Pin; PinHeader_1x03_P2.54mm_Vertical
J2: Conn_01x02_Pin; PinHeader_1x02_P2.54mm_Vertical
JP1, JP3: SolderJumper_2_Open; SolderJumper-2_P1.3mm_Open_RoundedPad1.0x1.5mm
R1, R3: 5.1k; R_0603_1608Metric_Pad0.98x0.95mm_HandSolder
U1: TPS60403DBV; SOT-23-5
U2: AP2127K-3.3; SOT-23-5

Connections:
3V3: C5.1, JP1.2 (B), U2.5 (VOUT)
5V0: C2.1, C3.1, D1.1 (A1), F1.2, JP3.2 (B), U2.1 (VIN), U2.3 (EN)
5V0_RAW: F1.1, J2.1
GND: C1.2, C2.2, C3.2, C5.2, C6.2, C7.2, C8.2, D1.2 (A2), D4.2 (A), J1.3, J2.2, R1.2, U1.4 (GND), U2.2 (GND)
unnamed: D2.1 (K), R1.1
unnamed: D4.1 (K), R3.1
unnamed: C4.1, U1.5 (C_{FLY+})
unnamed: C4.2, U1.3 (C_{FLY-})
VCC: C1.1, C8.1, D2.2 (A), J1.1, JP1.1 (A), JP3.1 (A), U1.2 (IN)
VEE: C6.1, C7.1, J1.2, R3.2, U1.1 (OUT)

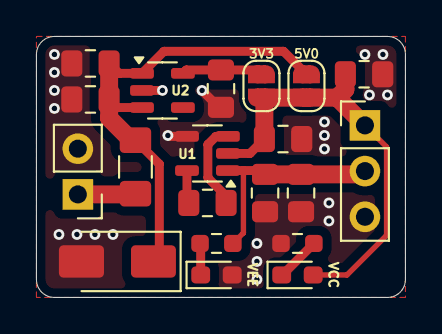
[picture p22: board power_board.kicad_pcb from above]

Board: 2 copper layers, 20.5 x 14.5 mm, 20 parts (0 on the bottom side), 10 nets.

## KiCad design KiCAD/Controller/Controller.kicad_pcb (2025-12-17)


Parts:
C1, C2, C3, C4, C5, C6, C7, C8, C9, C10: 4.7u; C_0805_2012Metric_Pad1.18x1.45mm_HandSolder
C11, C12, C13, C14, C15, C16: 100n; C_0603_1608Metric_Pad1.08x0.95mm_HandSolder
D1: SMAJ5.0A; D_SMA
D2, D3, D4, D5, D6, D7, D8, D9, D10, D11, D12: LED; LED_0603_1608Metric_Pad1.05x0.95mm_HandSolder
F1: Polyfuse; Fuse_1206_3216Metric_Pad1.42x1.75mm_HandSolder
H1, H2, H3, H4: MountingHole; MountingHole_3.2mm_M3
J1: Conn_ST_STDC14; PinHeader_2x07_P1.27mm_Vertical
J2: USB_C_Receptacle_USB2.0_16P; USB_C_Receptacle_GCT_USB4105-xx-A_16P_TopMnt_Horizontal
J3: Conn_01x02_Pin; PinHeader_1x02_P2.54mm_Vertical
J4, J5, J6: Conn_01x03_Pin; PinHeader_1x03_P2.54mm_Vertical
JP1, JP2, JP3: SolderJumper_2_Open; SolderJumper-2_P1.3mm_Open_RoundedPad1.0x1.5mm
R1, R2, R3, R4, R5: 100; R_0603_1608Metric_Pad0.98x0.95mm_HandSolder
R6, R7, R8, R9, R10, R11, R12, R13, R14, R15, R16, R17, R18: 5.1k; R_0603_1608Metric_Pad0.98x0.95mm_HandSolder
SW1, SW2, SW3: SW_Push; SW_SPST_PTS647_Sx38
U1: STM32G0B1CBTx; LQFP-48_7x7mm_P0.5mm
U2: AP2127K-3.3; SOT-23-5
U3: TPS60403DBV; SOT-23-5
U4: USBLC6-2SC6; SOT-23-6

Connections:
3V3: C3.1, C4.1, C14.1, D11.2 (A), J1.3 (VCC), JP1.2 (B), U1.6 (VDD), U2.5 (VOUT)
5V0: C1.1, C2.1, D1.1 (A1), D10.2 (A), F1.2, JP2.2 (B), U2.1 (VIN), U2.3 (EN)
5V0_RAW: F1.1, J3.1, JP3.1 (A)
5V0_USB: J2.A4 (VBUS), J2.A9 (VBUS), J2.B4 (VBUS), J2.B9 (VBUS), JP3.2 (B)
/LED_PS_SELECT_0: D6.2 (A), U1.21 (PB2)
/LED_PS_SELECT_1: D7.2 (A), U1.22 (PB10)
/LED_PS_SELECT_2: D8.2 (A), U1.23 (PB11)
/LED_PS_SELECT_3: D9.2 (A), U1.24 (PB12)
/LED_PS_STATE_0: D2.2 (A), U1.16 (PA5)
/LED_PS_STATE_1: D3.2 (A), U1.17 (PA6)
/LED_PS_STATE_2: D4.2 (A), U1.18 (PA7)
/LED_PS_STATE_3: D5.2 (A), U1.19 (PB0)
/PS_LE: J6.3, U1.45 (PB6)
/SPI2_MOSI: J6.1, U1.46 (PB7)
/SPI2_SCK: J6.2, U1.47 (PB8)
/SW0: C11.1, SW1.2, U1.13 (PA2)
/SW1: C12.1, SW2.2, U1.14 (PA3)
/SW2: C13.1, SW3.2, U1.15 (PA4)
/SYS_SWCLK: R3.2, U1.36 (PA14)
/SYS_SWDIO: R2.2, U1.35 (PA13)
/USART4_RX: J4.2, U1.12 (PA1)
/USART4_TX: J4.1, U1.11 (PA0)
/USART5_RX: R4.2, U1.43 (PB4)
/USART5_TX: R5.2, U1.42 (PB3)
/USB_DN: U1.33 (PA9/PA11), U4.6 (I/O1)
/USB_DP: U1.34 (PA10/PA12), U4.4 (I/O2)
/nRST: R1.2, U1.10 (PF2)
GND: C1.2, C2.2, C3.2, C4.2, C6.2, C7.2, C8.2, C9.2, C10.2, C11.2, C12.2, C13.2, C14.2, C15.2, C16.2, D1.2 (A2), D12.2 (A), J1.5 (GND), J1.7 (GND), J1.11 (GNDDetect), J2.A1 (GND), J2.A12 (GND), J2.B1 (GND), J2.B12 (GND), J2.S1 (SHIELD), J3.2, J4.3, J5.3, R6.2, R7.2, R8.2, R9.2, R10.2, R11.2, R12.2, R13.2, R14.2, R15.2, R16.2, R17.2, SW1.1, SW2.1, SW3.1, U1.7 (VSS), U2.2 (GND), U3.4 (GND)
unnamed: D2.1 (K), R8.1
unnamed: D3.1 (K), R9.1
unnamed: D4.1 (K), R10.1
unnamed: D5.1 (K), R11.1
unnamed: D6.1 (K), R12.1
unnamed: D7.1 (K), R13.1
unnamed: D8.1 (K), R14.1
unnamed: D9.1 (K), R15.1
unnamed: D10.1 (K), R16.1
unnamed: D11.1 (K), R17.1
unnamed: D12.1 (K), R18.1
unnamed: J1.6 (JCLK/SWCLK), R2.1
unnamed: J1.4 (JTMS/SWDIO), R3.1
unnamed: J1.13 (VCP_RX), R4.1
unnamed: J1.14 (VCP_TX), R5.1
unnamed: J1.12 (~RST), R1.1
unnamed: J2.A5 (CC1), R7.1
unnamed: J2.B5 (CC2), R6.1
unnamed: J2.A6 (D+), J2.B6 (D+), U4.3 (I/O2)
unnamed: J2.A7 (D-), J2.B7 (D-), U4.1 (I/O1)
unnamed: C5.1, U3.5 (C_{FLY+})
unnamed: C5.2, U3.3 (C_{FLY-})
VBAT: C15.1, U1.4 (VBAT)
VCC: C8.1, C9.1, J5.1, JP1.1 (A), JP2.1 (A), U3.2 (IN)
VEE: C6.1, C7.1, C10.1, J5.2, R18.2, U3.1 (OUT)
VREF+: C16.1, U1.5 (VREF+)



Board: 2 copper layers, 54.0 x 35.0 mm, 67 parts (24 on the bottom side), 54 nets.

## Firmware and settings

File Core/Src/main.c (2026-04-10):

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
/* Includes ------------------------------------------------------------------*/
#include "main.h"
#include "spi.h"
#include "usart.h"
#include "usb_device.h"
#include "gpio.h"

/* USER CODE BEGIN Includes */
#include "beam_controller.h"
#include "util/soft_timer.h"
/* USER CODE END Includes */


/* USER CODE BEGIN PV */
beam_controller_t controller;
/* USER CODE END PV */

void SystemClock_Config(void);
/**
  * @brief  The application entry point.
  * @retval int
  */
int main(void)
{

  /* MCU Configuration--------------------------------------------------------*/

  /* Reset of all peripherals, Initializes the Flash interface and the Systick. */
  HAL_Init();

  /* Configure the system clock */
  SystemClock_Config();

  /* Initialize all configured peripherals */
  MX_GPIO_Init();
  MX_SPI2_Init();
  MX_USART4_UART_Init();
  MX_USART5_UART_Init();
  MX_USB_Device_Init();
  /* USER CODE BEGIN 2 */

  beam_controller_config_t controller_config = {
      .hspi = &hspi2
  };
  
  beam_controller_init(&controller, &controller_config);

  /* USER CODE END 2 */

  /* Infinite loop */
  /* USER CODE BEGIN WHILE */
  while (1)
  {
    beam_controller_update(&controller);
    soft_timer_update_all(controller.soft_timers, SOFT_TIMER_COUNT);
    /* USER CODE END WHILE */

    /* USER CODE BEGIN 3 */
  }
  /* USER CODE END 3 */
}

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


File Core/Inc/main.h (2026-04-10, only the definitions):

#define PS_LATCH_Pin GPIO_PIN_2
#define PS_LATCH_GPIO_Port GPIOA
#define PS_LATCH_EXTI_IRQn EXTI2_3_IRQn
#define PS_SELECT_Pin GPIO_PIN_3
#define PS_SELECT_GPIO_Port GPIOA
#define PS_SELECT_EXTI_IRQn EXTI2_3_IRQn
#define PS_PHASE_Pin GPIO_PIN_4
#define PS_PHASE_GPIO_Port GPIOA
#define PS_PHASE_EXTI_IRQn EXTI4_15_IRQn
#define LED_PS_SELECT_0_Pin GPIO_PIN_5
#define LED_PS_SELECT_0_GPIO_Port GPIOA
#define LED_PS_SELECT_1_Pin GPIO_PIN_6
#define LED_PS_SELECT_1_GPIO_Port GPIOA
#define LED_PS_SELECT_2_Pin GPIO_PIN_7
#define LED_PS_SELECT_2_GPIO_Port GPIOA
#define LED_PS_SELECT_3_Pin GPIO_PIN_0
#define LED_PS_SELECT_3_GPIO_Port GPIOB
#define LED_PS_STATE_0_Pin GPIO_PIN_2
#define LED_PS_STATE_0_GPIO_Port GPIOB
#define LED_PS_STATE_1_Pin GPIO_PIN_10
#define LED_PS_STATE_1_GPIO_Port GPIOB
#define LED_PS_STATE_2_Pin GPIO_PIN_11
#define LED_PS_STATE_2_GPIO_Port GPIOB
#define LED_PS_STATE_3_Pin GPIO_PIN_12
#define LED_PS_STATE_3_GPIO_Port GPIOB
#define LE_Pin GPIO_PIN_6
#define LE_GPIO_Port GPIOB

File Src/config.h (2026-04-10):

#pragma once

#define MAX_PHASE_SHIFTER_COUNT 8
#define PHASE_SHIFTER_COUNT 4

#define MAX_PHASE_SHIFTER_BIT_RESOLUTION 6
#define PHASE_SHIFTER_BIT_RESOLUTION 4

/*
    SOFT TIMERS CONFIGURATION
*/

#define DEBOUNCE_DURATION_MS 50

#define PS_SELECT_BUTTON_DEBOUNCE_TIMER_ID 0
#define PS_PHASE_BUTTON_DEBOUNCE_TIMER_ID 1
#define PS_LATCH_BUTTON_DEBOUNCE_TIMER_ID 2

#define LONG_PRESS_DURATION_MS 1000

#define PS_SELECT_BUTTON_LONG_PRESS_TIMER_ID 3
#define PS_PHASE_BUTTON_LONG_PRESS_TIMER_ID 4
#define PS_LATCH_BUTTON_LONG_PRESS_TIMER_ID 5

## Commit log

2025-05-15 stm32 project
2025-06-26 basic spi, cmake
2025-06-27 Initial UART communication
2025-06-28 basic spi interfaceing
2025-06-30 DONE :)
    [Phase_shifter.kicad_pcb, Phase_shifter.kicad_sch]
2025-09-16 phase shifter
    [Phase_shifter_test_board.kicad_pcb, Phase_shifter_test_board.kicad_sch]
2025-09-24 test board
    [Phase_shifter_test_board.kicad_pcb, Phase_shifter_test_board.kicad_sch]
2025-12-17 Working and tested
    [Antenna_array.kicad_pcb, Antenna_array.kicad_sch]
2026-04-10 Board bring up (#2)
    * recreated project
    * remake
    * soft timer tested
    * debug
    * operation queue
    * led indicator
    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

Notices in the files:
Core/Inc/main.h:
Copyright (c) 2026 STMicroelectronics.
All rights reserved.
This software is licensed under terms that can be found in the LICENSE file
